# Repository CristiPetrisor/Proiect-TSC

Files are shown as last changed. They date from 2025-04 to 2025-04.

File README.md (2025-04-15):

# OpenBook E-Reader - Readme

**Proiect TSC - Caramida-Stoian Petrisor-Cristian**

## Prezentare pe scurt

OpenBook este un e-reader open-source bazat pe ESP32-C6, dotat cu ecran e-paper de 7.5", senzori de mediu, sistem de alimentare cu baterie și conectivitate Wi-Fi și USB-C. Documentul prezintă structura hardware și componentele integrate.

## Diagramă Bloc

```
           +-------------------------+
           |         Battery          |
           +------------+------------+
                        |
                        v
           +-------------------------+
           |     Charging IC (USB-C)  |
           +------------+------------+
                        |
                        v
           +-------------------------+
           |         LDO              |  ---> 3.3V
           +------------+------------+
                        |
     +------------------+-------------------+------------------+
     |                  |                   |                  |
     v                  v                   v                  v
+------------+   +--------------+   +---------------+   +-----------------+
|   ESP32    |<->|    Display   |<->|    BME688     |<->|  Tactile Buttons|
|    -C6     |   |   (SPI: 4W)   |   |   (I2C Bus)   |   |   (GPIO + RC)   |
+------------+   +--------------+   +---------------+   +-----------------+
     |                  ^                    ^                    ^
     |                  |                    |                    |
     |                  |              Pull-up Resistors     Debouncing RC
     |                  |
     v                  |
+----------------------------+
|      USB-C Connector       |
| (USB Data ↔ ESP32 USB)     |
| (ESD & Termination Prot.)  |
+----------------------------+
```

## Lista BOM

| **Componentă** | **Part Number** | **Descriere** | **Furnizor (Mouser)** | **Datasheet** |
|---|---|---|---|---|
| 1 | ADAFRUIT_LEDCHIP-LED0603 | - | LED | ADAFRUIT_CHIP-LED0603 | CHG_LED | [link](https://www.mouser.com/ProductDetail/Adafruit/CHIP-LED0603) | [datasheet](https://www.mouser.com/datasheet/2/737/CHIP-LED0603-1877199.pdf) |
| 1 | SJ | - | SMD solder JUMPER | SJ | SJ1 | [link](https://www.mouser.com/ProductDetail/TE-Connectivity/1-2176091-2) | [datasheet](https://www.mouser.com/datasheet/2/418/1-2176091-2-1817091.pdf) |
| 1 | ESP32_WROVER_EAGLE-LTSPICE_RR0402  | 0.47Ω | Rezistor | ESP32_WROVER_EAGLE-LTSPICE_R0402| R3 | [link](https://www.mouser.com/ProductDetail/Vishay/CRCW04020047ZRT7) | [datasheet](https://www.mouser.com/datasheet/2/427/crcwce-1764191.pdf) |
| 1 | ESP32_WROVER_EAGLE-LTSPICE_RR0402  | 100KΩ | Rezistor | ESP32_WROVER_EAGLE-LTSPICE_R0402| R1_PWRUSB | [link](https://www.mouser.com/ProductDetail/Vishay/CRCW0402100KFKED) | [datasheet](https://www.mouser.com/datasheet/2/427/crcwce-1764191.pdf) |
| 8 | EAGLE-LTSPICE_CC0402 | 100nF | Condensator | EAGLE-LTSPICE_C0402 | C1, C2, C4_USB, C6, C8, C9, C10, C_DELAY | [link](https://www.mouser.com/ProductDetail/Murata/GRM155R71C104KA88D) | [datasheet](https://www.mouser.com/datasheet/2/281/GRM155R71C104KA88D-1767201.pdf) |
| 1 | RCL_CPOL-EUCT3528 | 100µF | Condensator polarizat | RCL_CT3528 | C3 | [link](https://www.mouser.com/ProductDetail/Panasonic/EEE-FK1V101P) | [datasheet](https://www.mouser.com/datasheet/2/315/EEE-FK1V101P-1526881.pdf) |
| 10 | ESP32_WROVER_EAGLE-LTSPICE_RR0402  | 10KΩ | Rezistor | ESP32_WROVER_EAGLE-LTSPICE_R0402| R1, R1-PINH, R1_PINH1, R2-PINH, R2_PINH1, R4, R_BOOT, R_CHANGE, R_CL1, R_RESET | [link](https://www.mouser.com/ProductDetail/Vishay/CRCW040210K0FKED) | [datasheet](https://www.mouser.com/datasheet/2/427/crcwce-1764191.pdf) |
| 6 | ESP32_WROVER_EAGLE-LTSPICE_RR0402  | 10kΩ | Rezistor | ESP32_WROVER_EAGLE-LTSPICE_R0402| R5, R6, R7, R8, R9, R10 | [link](https://www.mouser.com/ProductDetail/Vishay/CRCW040210K0FKED) | [datasheet](https://www.mouser.com/datasheet/2/427/crcwce-1764191.pdf) |
| 1 | EAGLE-LTSPICE_CC0402 | 10µF | Condensator | EAGLE-LTSPICE_C0402 | C7 | [link](https://www.mouser.com/ProductDetail/Murata/GRM155R61A106ME44D) | [datasheet](https://www.mouser.com/datasheet/2/281/GRM155R61A106ME44D-1767201.pdf) |
| 1 | 112A-TAAR-R03_ATTEND | - | Micro SD Card Socket, Push-Push Type | 112ATAARR03ATTEND | J4 | [link](https://www.mouser.com/ProductDetail/Attend/112A-TAAR-R03) | [datasheet](https://www.mouser.com/datasheet/2/828/112A-TAAR-R03-1222862.pdf) |
| 1 | ESP32_WROVER_EAGLE-LTSPICE_RR0402  | 15Ω | Rezistor | ESP32_WROVER_EAGLE-LTSPICE_R0402| R_CAPACITOR  | [link](https://www.mouser.com/ProductDetail/Vishay/CRCW040215R0FKED) | [datasheet](https://www.mouser.com/datasheet/2/427/crcwce-1764191.pdf) |
| 1 | EAGLE-LTSPICE_CC0402 | 1µF | Condensator | EAGLE-LTSPICE_C0402 | C5 | [link](https://www.mouser.com/ProductDetail/Murata/GRM155R61A105KE15D) | [datasheet](https://www.mouser.com/datasheet/2/281/GRM155R61A105KE15D-1767201.pdf) |
| 10 | EAGLE-LTSPICE_CC0402 | 1µF/50V | Condensator ceramic multi-strat | 0402 | EPD_C1, EPD_C2, EPD_C5, EPD_C6, EPD_C7, EPD_C8, EPD_C9, EPD_C10, EPD_C11, EPD_C12 | [link](https://www.mouser.com/ProductDetail/Murata-Electronics/GRM155R61A105KE15D) | [datasheet](https://www.mouser.com/datasheet/2/281/1/GRM155R61A105KE15_01A-1983730.pdf) |

---

## Detalii Functionalitate Hardware

## ESP32-C6-WROOM-1-N8

- **Rol**: Controler principal, conectivitate wireless și suport periferice.
- **Specificații**: 160MHz, 512KB SRAM, 8MB Flash.
- **Interfețe**:
  - **SPI**: Display e-paper, memorie Flash, card Micro SD.
  - **I2C**: Senzor BME680, monitorizare baterie (MAX17048), RTC (DS3231).
  - **GPIO**: Interacțiune cu butoane și LED-uri.
  - **UART**: Debugging și comunicare serială.

## Senzor BME680

- **Funcționalitate**: Măsoară temperatură, umiditate, presiune atmosferică și calitate aer.
- **Interfață**: I2C la 400kHz.
- **Consum**: Sub 1mA activ, sub 1µA în repaus.

## Sistem de Alimentare

- **Baterie**: Li-Po 2500mAh, 3.7V.
- **Încărcare**: Controlată de MCP73831 prin USB-C, cu capacitate de 1A.
- **Monitorizare**: MAX17048 prin I2C.
- **Consum energetic**:
  - Activ (Wi-Fi + ecran actualizat): ~150mA.
  - Standby (doar ecran afișat): ~10mA.
  - Deep Sleep: Sub 50µA.
  - **Autonomie estimată**: Aproximativ o săptămână (~250 ore cu un consum mediu de 10mA).

## Display E-Paper
  
-Dimensiune: 7.5 inch, cu o rezoluție de 800x480 pixeli și un contrast de 8:1.
-Conectivitate: Se conectează prin interfața SPI și are linii dedicate pentru control și resetare.
-Consum de energie: Sub 50mA în timpul actualizării imaginii și aproape zero în modul standby.

## Butoane de Navigare

- Butoane tactile Panasonic EVQPUJ02K cu rezistență pull-up de 10KΩ.

## USB-C

- **Rol**: Încărcare (5V/1A) și transfer de date (USB 2.0).
- **Protecție**: Diode ESD (USBLC6-2SC6Y) pentru siguranță la supratensiune.

## Configurare Pini ESP32-C6

| **Pin ESP32-C6** | **Funcție** | **Componentă** | **Rol** |
|---|---|---|---|
| GPIO0 | BOOT_BUTTON | Buton | Mod boot la inițializare |
| GPIO1 | RESET_BUTTON | Buton | Reset manual |
| GPIO2 | CHANGE_BUTTON | Buton | Schimbare meniuri |
| GPIO3 | EPD_CS | Display E-Paper | Chip Select pentru SPI |
| GPIO4 | EPD_DC | Display E-Paper | Control Date/Comenzi |
| GPIO5 | EPD_RST | Display E-Paper | Reset display |
| GPIO6 | EPD_BUSY | Display E-Paper | Detectare stare refresh |
| GPIO7 | SPI_MOSI | Display, Flash, SD | Linii de date SPI |
| GPIO8 | SPI_MISO | Display, Flash, SD | Linie de date SPI (citire) |
| GPIO9 | SPI_SCK | Display, Flash, SD | Semnal de ceas SPI |
| GPIO10 | FLASH_CS | Memorie Flash | Chip Select pentru memorie |
| GPIO11 | SD_CS | Card Micro SD | Chip Select pentru card SD |
| GPIO12 | I2C_SDA | BME680, MAX17048, DS3231 | Linie de date pentru I2C |
| GPIO13 | I2C_SCL | BME680, MAX17048, DS3231 | Linie de ceas pentru I2C |
| GPIO14 | CHG_LED | LED | Indică procesul de încărcare |
| GPIO15 | UART_TX | Debugging | Transmitere date seriale |
| GPIO16 | UART_RX | Debugging | Recepție date seriale |
| GPIO17 | USB_D+ | USB-C | Linie de date USB pozitivă |
| GPIO18 | USB_D- | USB-C | Linie de date USB negativă |

Notă: Pinii sunt alocați conform specificațiilor ESP32-C6 și cerințelor dispozitivului OpenBook. Anumiți pini sunt multifuncționali și pot fi utilizați în diferite configurații.

Poze Schematic si PCB 






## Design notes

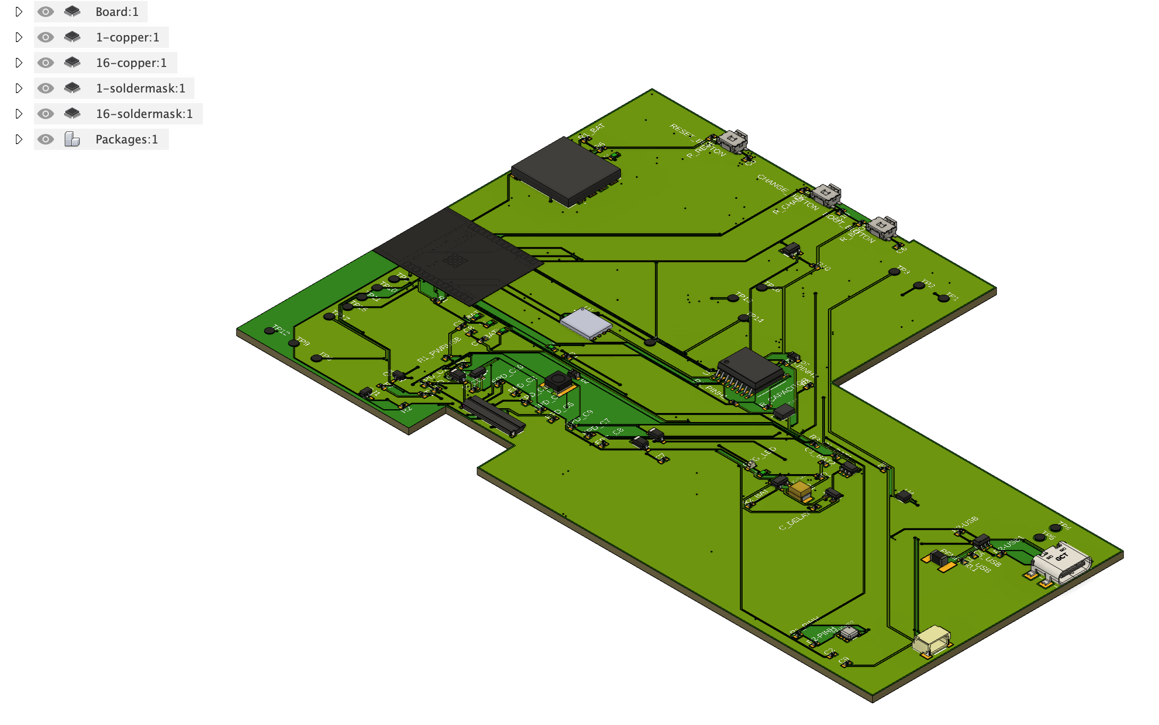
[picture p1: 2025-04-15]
Images/Screenshot 2025-04-15 at 20.33.14.png

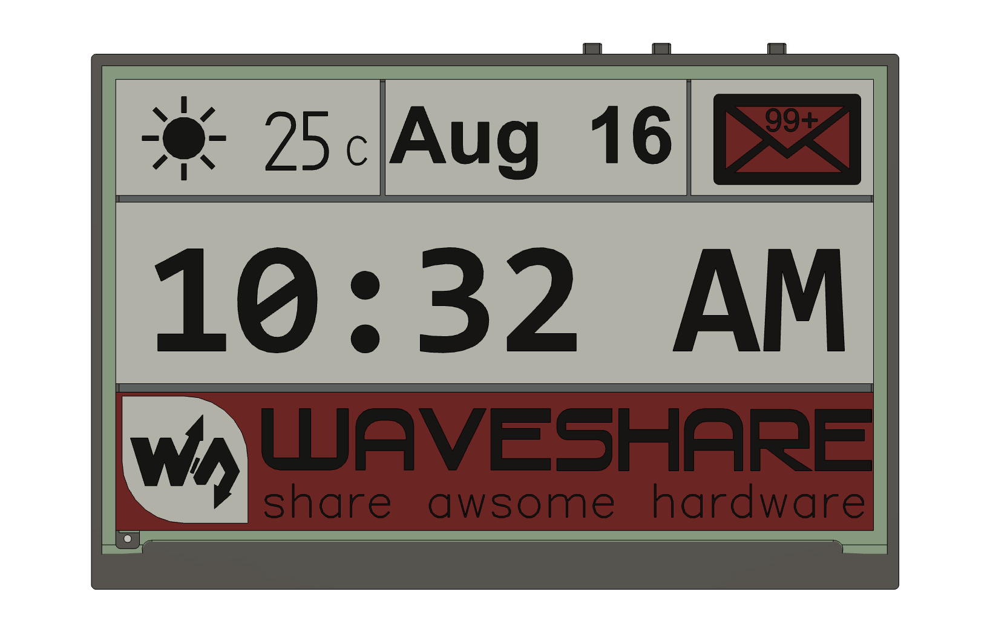
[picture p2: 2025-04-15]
Images/Screenshot 2025-04-15 at 20.50.41.png

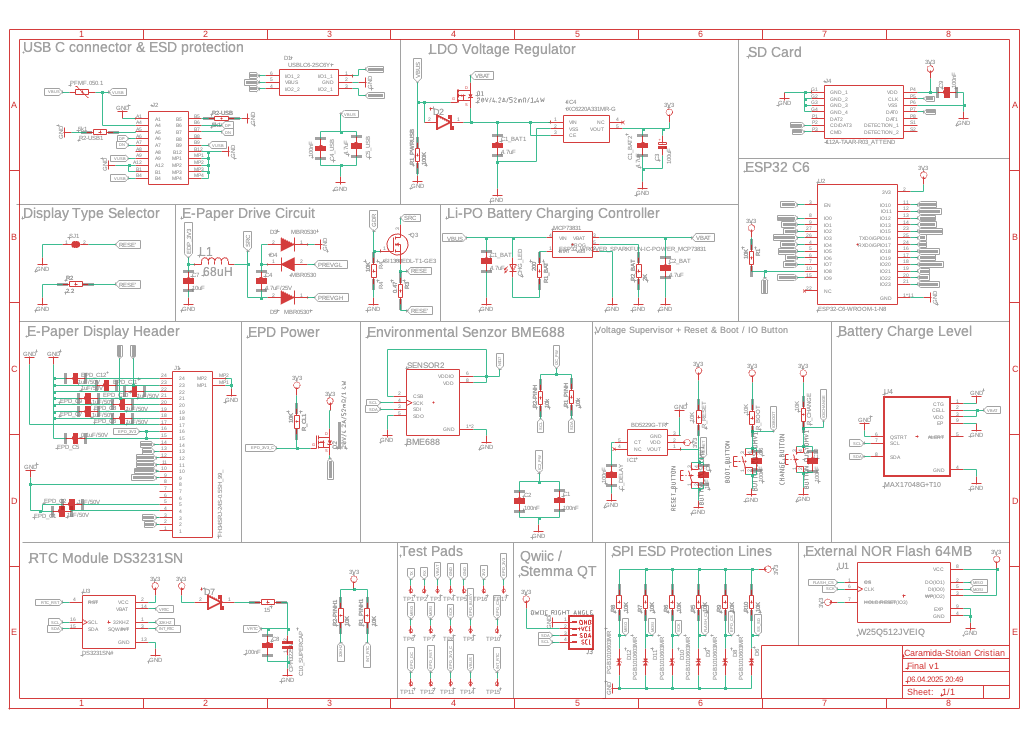
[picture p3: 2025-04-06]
Images/Sch.png

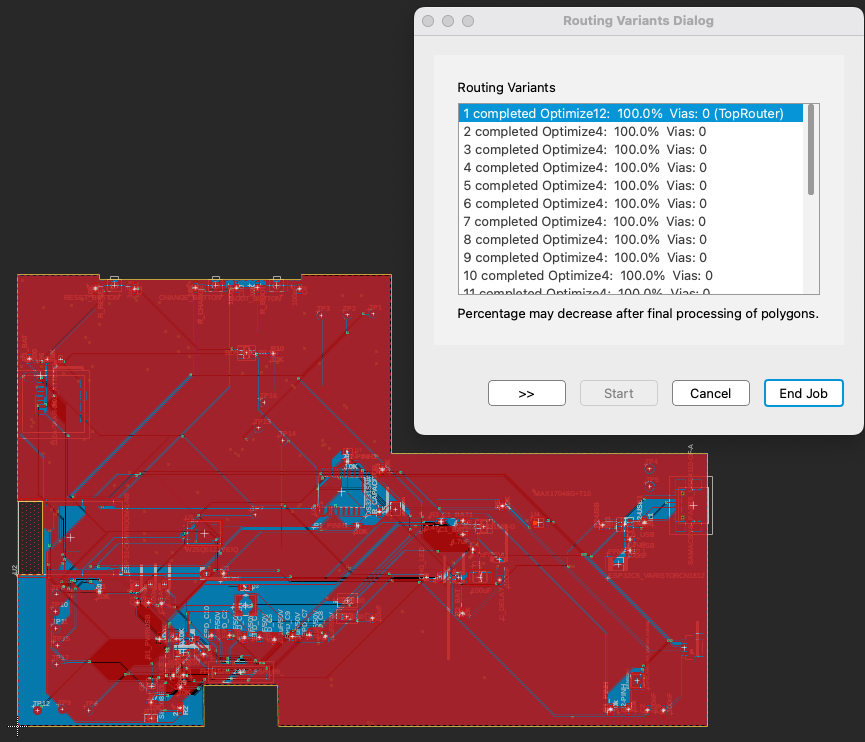
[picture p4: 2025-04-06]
Images/PCB.png

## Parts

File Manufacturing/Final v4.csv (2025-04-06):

Qty | Value | Device | Package | Parts | Description | ARROW_PART_NUMBER | ARROW_PRICE-STOCK | AVAILABILITY | CENTROID_NOT_SPECIFIED | CHECK_PRICES | COPYRIGHT | DATASHEET | DESCRIPTION | DIGIKEY_DESCRIPTION | DIGIKEY_PART_NUMBER | HEIGHT | LEAD_FREE | MANUFACTURER_NAME | MANUFACTURER_PART_NUMBER | MF | MFR_NAME | MOUSER_PART_NUMBER | MOUSER_PRICE-STOCK | MOUSER_TESTING_PART_NUMBER | MOUSER_TESTING_PRICE-STOCK | MP | MPN | PACKAGE | POPULARITY | PREFIX | PRICE | PROD_ID | PURCHASE-URL | ROHS | SNAPEDA_LINK | SPICEMODEL | SPICEPREFIX | TEMPERATURE_RANGE_HIGH | TEMPERATURE_RANGE_LOW | TP_SIGNAL_NAME | VALUE
1 |  | ADAFRUIT_LEDCHIP-LED0603 | ADAFRUIT_CHIP-LED0603 | CHG_LED | LED
1 |  | SJ | SJ | SJ1 | SMD solder JUMPER |  |  |  |  |  |  |  |  |  |  |  |  |  |  |  |  |  |  |  |  |  |  |  | 3
1 | 0.1uF/50V | EAGLE-LTSPICE_CC0402 | EAGLE-LTSPICE_C0402 | EPD_C5 | CAPACITOR, European symbol |  |  |  |  |  |  |  |  |  |  |  |  |  |  |  |  |  |  |  |  |  |  |  |  |  |  |  |  |  |  | NONE | C
1 | 0.47 | ESP32_WROVER_EAGLE-LTSPICE_RR0402 | ESP32_WROVER_EAGLE-LTSPICE_R0402 | R3 | RESISTOR, European symbol |  |  |  |  |  |  |  |  |  |  |  |  |  |  |  |  |  |  |  |  |  |  |  |  |  |  |  |  |  |  | NONE | R
1 | 100K | ESP32_WROVER_EAGLE-LTSPICE_RR0402 | ESP32_WROVER_EAGLE-LTSPICE_R0402 | R1_PWRUSB | RESISTOR, European symbol |  |  |  |  |  |  |  |  |  |  |  |  |  |  |  |  |  |  |  |  |  |  |  |  |  |  |  |  |  |  | NONE | R
2 | 100nF | EAGLE-LTSPICE_CC0402 | EAGLE-LTSPICE_C0402 | C6, C10 | CAPACITOR, European symbol |  |  |  |  |  |  |  |  |  |  |  |  |  |  |  |  |  |  |  |  |  |  |  |  |  |  |  |  |  |  | NONE | C
6 | 100nF | ESP32_WROVER_EAGLE-LTSPICE_CC0402 | ESP32_WROVER_EAGLE-LTSPICE_C0402 | C1, C2, C4_USB, C8, C9, C_DELAY | CAPACITOR, European symbol |  |  |  |  |  |  |  |  |  |  |  |  |  |  |  |  |  |  |  |  |  |  |  |  |  |  |  |  |  |  | NONE | C
1 | 100uF | RCL_CPOL-EUCT3528 | RCL_CT3528 | C3 | POLARIZED CAPACITOR, European symbol |  |  |  |  |  |  |  |  |  |  |  |  |  |  |  |  |  |  |  |  |  |  |  | 0 |  |  |  |  |  |  |  | C
14 | 10K | ESP32_WROVER_EAGLE-LTSPICE_RR0402 | ESP32_WROVER_EAGLE-LTSPICE_R0402 | R1, R1_PINH1, R2-PINH1, R4, R5, R6, R7, R8, R9, R10, R_BOOT, R_CHANGE, R_CL1, R_RESET | RESISTOR, European symbol |  |  |  |  |  |  |  |  |  |  |  |  |  |  |  |  |  |  |  |  |  |  |  |  |  |  |  |  |  |  | NONE | R
2 | 10k | ESP32_WROVER_EAGLE-LTSPICE_RR0402 | ESP32_WROVER_EAGLE-LTSPICE_R0402 | R1_PINH, R2-PINH | RESISTOR, European symbol |  |  |  |  |  |  |  |  |  |  |  |  |  |  |  |  |  |  |  |  |  |  |  |  |  |  |  |  |  |  | NONE | R
1 | 10uF | ESP32_WROVER_EAGLE-LTSPICE_CC0402 | ESP32_WROVER_EAGLE-LTSPICE_C0402 | C7 | CAPACITOR, European symbol |  |  |  |  |  |  |  |  |  |  |  |  |  |  |  |  |  |  |  |  |  |  |  |  |  |  |  |  |  |  | NONE | C
1 | 112A-TAAR-R03_ATTEND | 112A-TAAR-R03_ATTEND | 112ATAARR03ATTEND | J4 | Micro SD Card Socket, Push-Push Type, Top Mount, SMT, H=1.83mm, 10u |  |  |  |  |  |  |  | Micro SD Card Socket | Push-Push Type | Top Mount | SMT | H=1.83mm | 10u |  |  | 1.9mm |  | ATTEND | 112A-TAAR-R03 ATTEND
1 | 15 | ESP32_WROVER_EAGLE-LTSPICE_RR0402 | ESP32_WROVER_EAGLE-LTSPICE_R0402 | R_CAPACITOR | RESISTOR, European symbol |  |  |  |  |  |  |  |  |  |  |  |  |  |  |  |  |  |  |  |  |  |  |  |  |  |  |  |  |  |  | NONE | R
1 | 1uF | EAGLE-LTSPICE_CC0402 | EAGLE-LTSPICE_C0402 | C5 | CAPACITOR, European symbol |  |  |  |  |  |  |  |  |  |  |  |  |  |  |  |  |  |  |  |  |  |  |  |  |  |  |  |  |  |  | NONE | C
9 | 1uF/50V | EAGLE-LTSPICE_CC0402 | EAGLE-LTSPICE_C0402 | EPD_C1, EPD_C2, EPD_C6, EPD_C7, EPD_C8, EPD_C9, EPD_C10, EPD_C11, EPD_C12 | CAPACITOR, European symbol |  |  |  |  |  |  |  |  |  |  |  |  |  |  |  |  |  |  |  |  |  |  |  |  |  |  |  |  |  |  | NONE | C
1 | 2.2 | ESP32_WROVER_EAGLE-LTSPICE_RR0402 | ESP32_WROVER_EAGLE-LTSPICE_R0402 | R2 | RESISTOR, European symbol |  |  |  |  |  |  |  |  |  |  |  |  |  |  |  |  |  |  |  |  |  |  |  |  |  |  |  |  |  |  | NONE | R
1 | 200 | ESP32_WROVER_EAGLE-LTSPICE_RR0402 | ESP32_WROVER_EAGLE-LTSPICE_R0402 | R1_BAT | RESISTOR, European symbol |  |  |  |  |  |  |  |  |  |  |  |  |  |  |  |  |  |  |  |  |  |  |  |  |  |  |  |  |  |  | NONE | R
2 | 20V/4.2A/52mΩ/1.4W | ESP32_WROVER_SPARKFUN-DISCRETESEMI_MOSFET_PCH-DMG2305UX-7 | ESP32_WROVER_SPARKFUN-DISCRETESEMI_SOT23-3 | Q1, Q2 | P-channel MOSFETs |  |  |  |  |  |  |  |  |  |  |  |  |  |  |  |  |  |  |  |  |  |  |  |  |  |  | TRAN-14388 |  |  |  |  |  |  |  |  | 20V/4.2A/52mΩ/1.4W
1 | 2K | ESP32_WROVER_EAGLE-LTSPICE_RR0402 | ESP32_WROVER_EAGLE-LTSPICE_R0402 | R2_BAT | RESISTOR, European symbol |  |  |  |  |  |  |  |  |  |  |  |  |  |  |  |  |  |  |  |  |  |  |  |  |  |  |  |  |  |  | NONE | R
5 | 4.7uF | ESP32_WROVER_EAGLE-LTSPICE_CC0402 | ESP32_WROVER_EAGLE-LTSPICE_C0402 | C1_BAT, C1_BAT1, C1_BAT2, C2_BAT, C5_USB | CAPACITOR, European symbol |  |  |  |  |  |  |  |  |  |  |  |  |  |  |  |  |  |  |  |  |  |  |  |  |  |  |  |  |  |  | NONE | C
1 | 4.7uF/25V | ESP32_WROVER_EAGLE-LTSPICE_CC0402 | ESP32_WROVER_EAGLE-LTSPICE_C0402 | C4 | CAPACITOR, European symbol |  |  |  |  |  |  |  |  |  |  |  |  |  |  |  |  |  |  |  |  |  |  |  |  |  |  |  |  |  |  | NONE | C
2 | 5k1 | ESP32_WROVER_EAGLE-LTSPICE_RR0402 | ESP32_WROVER_EAGLE-LTSPICE_R0402 | R2-USB, R2-USB1 | RESISTOR, European symbol |  |  |  |  |  |  |  |  |  |  |  |  |  |  |  |  |  |  |  |  |  |  |  |  |  |  |  |  |  |  | NONE | R
1 | 68uH | 744043680IND_4828-WE-TPC_WRE | IND_4828-WE-TPC_WRE | L1 |  |  |  |  |  |  | Copyright (C) 2024 Ultra Librarian. All rights reserved. |  |  |  |  |  |  |  | 744043680 |  | Wurth Electronics
1 | BD5229G-TR | BD5229G-TR | SOT95P280X125-5N | IC1 | Voltage Detector with Adjustable Delay Time: CMOS processes are utilized to develop high precision, low current consumption CMOS reset ICs that allow arbitrary setting of the delay time. The extensive lineup includes both Nch Open Drain and CMOS output types in a wide range of detection voltages (from 2.3V to 6.0V, in 0.1V steps), enabling selection of the ideal solution based on customer requirements. In addition, the entire series is of course both lead-free and RoHS-compliant. |  |  |  |  |  |  |  | Voltage Detector with Adjustable Delay Time: CMOS processes are utilized to develop high precision | low current consumption CMOS reset ICs that allow arbitrary setting of the delay time. The extensive lineup includes both Nch Open Drain and CMOS output types in a wide range of detection voltages (from 2.3V to 6.0V | in 0.1V steps) | enabling selection of the ideal solution based on customer requirements. In addition | the entire series is of course both lead-free and RoHS-compliant. |  |  | 1.25mm |  | ROHM Semiconductor | BD5229G-TR |  |  | 755-BD5229G-TR | https://www.mouser.co.uk/ProductDetail/ROHM-Semiconductor/BD5229G-TR?qs=4kLU8WoGk0vvnhrrYwdszw%3D%3D
3 | BUTTON_CUSYOMV1 | BUTTON_CUSYOMV1 | MYBUTTON | BOOT_BUTTON, CHANGE_BUTTON, RESET_BUTTON
1 | CPH3225A | CPH3225A | CAPCP3225X100N | C10_SUPERCAP | Cap 0.011F 3.3V 1210 Flat Check availability |  |  | Not in stock |  | https://www.snapeda.com/parts/CPH3225A/Seiko+Instruments/view-part/?ref=eda |  |  | 11 mF (EDLC) Supercapacitor 3.3 V 1210 (3225 Metric) - - |  |  |  |  |  |  | Seiko Instruments |  |  |  |  |  | CPH3225A |  | 1210 Seiko |  |  | None |  | https://www.snapeda.com/api/url_track_click_mouser/?unipart_id=562593&manufacturer=Seiko Instruments&part_name=CPH3225A&search_term=None |  | https://www.snapeda.com/parts/CPH3225A/Seiko+Instruments/view-part/?ref=snap
1 | DS3231SN# | DS3231SN# | SOIC127P1032X265-16N | U3 | Real Time Clock Serial 16-Pin SOIC W T/R Check availability |  |  | In Stock |  | https://www.snapeda.com/parts/DS3231SN%23/Analog+Devices/view-part/?ref=eda |  |  | Extremely Accurate I²C-Integrated RTC/TCXO/Crystal |  |  |  |  |  |  | Analog Devices |  |  |  |  |  | DS3231SN# |  | SOIC-16 Maxim |  |  | None |  | https://www.snapeda.com/api/url_track_click_mouser/?unipart_id=99048&manufacturer=Analog Devices&part_name=DS3231SN#&search_term=None |  | https://www.snapeda.com/parts/DS3231SN%23/Analog+Devices/view-part/?ref=snap
1 | ESP32-C6-WROOM-1-N8 | ESP32-C6-WROOM-1-N8 | XCVR_ESP32-C6-WROOM-1-N8 | U2 | Check availability |  |  | In Stock |  | https://www.snapeda.com/parts/ESP32-C6-WROOM-1-N8/Espressif+Systems/view-part/?ref=eda |  |  | Multiprotocol Modules ESP32-C6 module | Wi-Fi 6 in 2.4 GHz band | Bluetooth 5 | Zigbee 3.0 and Thread. ESP34-WROOM Compatible - ENGINEERING SAMPLE |  |  |  |  |  |  | Espressif Systems |  |  |  |  |  | ESP32-C6-WROOM-1-N8 |  | None |  |  | None |  |  |  | https://www.snapeda.com/parts/ESP32-C6-WROOM-1-N8/Espressif+Systems/view-part/?ref=snap
1 | ESP32C6_VARISTORCN1812 | ESP32C6_VARISTORCN1812 | ESP32C6_VARISTOR_CT/CN1812 | PFMF.050.1 | VARISTOR |  |  |  |  |  |  |  |  |  |  |  |  |  |  |  |  |  |  |  |  |  |  |  | 0
2 | ESP32_WROVER_AVX---SD0805S020S1R0_AVX_SD0805S020S1R0_0_0AVX_SD0805S020S1R0_0_0 | ESP32_WROVER_AVX---SD0805S020S1R0_AVX_SD0805S020S1R0_0_0AVX_SD0805S020S1R0_0_0 | ESP32_WROVER_AVX---SD0805S020S1R0_AVX_SD0805S020S1R0_0 | D2, D7 | Schottky Barrier Rectifier Diode |  |  |  | No |  |  | http://datasheets.avx.com/schottky.pdf |  | DIODE SCHOTTKY 20V 1A 0805 | 478-7800-1-ND |  | yes |  |  | AVX |  | 581-SD0805S020S1R0 |  |  |  |  |  | 0805 (2012 metric) |  | D |  |  |  | yes |  |  |  | +125°C | -55°C
1 | ESP32_WROVER_BME680_BME680 | ESP32_WROVER_BME680_BME680 | ESP32_WROVER_BME680_PSON80P300X300X100-8N | SENSOR2 | Integrated Environmental Unit |  |  | Unavailable |  |  |  |  | Integrated Environmental Unit |  |  |  |  |  |  | Bosch Sensortec |  |  |  |  |  | BME680 |  | LGA-8 Bosch Tools |  |  | None
1 | ESP32_WROVER_SPARKFUN-IC-POWER_MCP73831 | ESP32_WROVER_SPARKFUN-IC-POWER_MCP73831 | ESP32_WROVER_SPARKFUN-IC-POWER_SOT23-5 | MCP73831 | MCP73831T Li-Ion, Li-Pol Controller |  |  |  |  |  |  |  |  |  |  |  |  |  |  |  |  |  |  |  |  |  |  |  |  |  |  | IC-09995
1 | FH34SRJ-24S-0.5SH_99_ | FH34SRJ-24S-0.5SH_99_ | FH34SRJ24S05SH99 | J1 | (0.50mm) Surface Mount, Right Angle |  |  |  |  |  |  |  | 24 Position FFC | FPC Connector Contacts | (0.50mm) Surface Mount | Right Angle |  |  | 1.1mm |  | Hirose | FH34SRJ-24S-0.5SH(99) |  |  | 798-FH34SRJ24S05SH99 | https://www.mouser.co.uk/ProductDetail/Hirose-Connector/FH34SRJ-24S-0.5SH99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
1 | MAX17048G+T10 | MAX17048G+T10 | SON50P200X200X80-9N | U4 | Check availability |  |  | In Stock |  | https://www.snapeda.com/parts/MAX17048G+T10/Analog+Devices/view-part/?ref=eda |  |  | 3µA 1-Cell/2-Cell Fuel Gauge with ModelGauge |  |  |  |  |  |  | Analog Devices |  |  |  |  |  | MAX17048G+T10 |  | TDFN-8 Maxim |  |  | None |  | https://www.snapeda.com/api/url_track_click_mouser/?unipart_id=329239&manufacturer=Analog Devices&part_name=MAX17048G+T10&search_term=None |  | https://www.snapeda.com/parts/MAX17048G+T10/Analog+Devices/view-part/?ref=snap
3 | MBR0530 | MBR0530 | SOD3716X135N | D3, D4, D5 | ON SEMICONDUCTOR - MBR0530 - DIODE, SCHOTTKY, 0.5A, 30V, SOD-123 |  |  | In Stock |  | https://www.snapeda.com/parts/MBR0530/Onsemi/view-part/?ref=eda |  |  | Diode Schottky 30 V 500mA Surface Mount SOD-123 |  |  |  |  |  |  | ON Semiconductor |  |  |  |  |  | MBR0530 |  | SOD-123-2 ON Semiconductor |  |  | None |  | https://www.snapeda.com/api/url_track_click_mouser/?unipart_id=179458&manufacturer=ON Semiconductor&part_name=MBR0530&search_term=None |  | https://www.snapeda.com/parts/MBR0530/Onsemi/view-part/?ref=snap
6 | PGB1010603MR | PGB1010603MR | DIOC1608X36N | D6, D8, D9, D10, D11, D12 | Check availability |  |  | In Stock |  | https://www.snapeda.com/parts/PGB1010603MR/Littelfuse/view-part/?ref=eda |  |  | 150V (Typ) Clamp - Ipp Tvs Diode Surface Mount 0603 (1608 Metric) |  |  |  |  |  |  | Littelfuse Inc. |  |  |  |  |  | PGB1010603MR |  | 0603 Littelfuse Inc. |  |  | None |  | https://www.snapeda.com/api/url_track_click_mouser/?unipart_id=5659453&manufacturer=Littelfuse Inc.&part_name=PGB1010603MR&search_term=None |  | https://www.snapeda.com/parts/PGB1010603MR/Littelfuse/view-part/?ref=snap
1 | QWIIC_RIGHT_ANGLE | QWIIC_CONNECTORJS-1MM | JST04_1MM_RA | J3 | SparkFun I2C Standard Qwiic Connector |  |  |  |  |  |  |  |  |  |  |  |  |  |  |  |  |  |  |  |  |  |  |  |  |  |  | CONN-13694 |  |  |  |  |  |  |  |  | QWIIC_RIGHT_ANGLE
1 | SAMACSYS_PARTS_USB4110-GF-A | SAMACSYS_PARTS_USB4110-GF-A | SAMACSYS_PARTS_USB4110GFA | J2 | CONN USB 2.0 TYPE-C R/A SMT |  |  |  |  |  |  |  | CONN USB 2.0 TYPE-C R/A SMT |  |  | 3.26mm |  | GCT (GLOBAL CONNECTOR TECHNOLOGY) | USB4110-GF-A |  |  | 640-USB4110-GF-A | https://www.mouser.co.uk/ProductDetail/GCT/USB4110-GF-A?qs=KUoIvG%2F9IlYiZvIXQjyJeA%3D%3D
1 | SI1308EDL-T1-GE3 | SI1308EDL-T1-GE3 | SOT65P210X110-3N | Q3 | MOSFET N-Ch 30V 1.5A TrenchFET SC70 Vishay Si1308EDL-T1-GE3 N-channel MOSFET Transistor, 1.5 A, 30 V, 3-Pin SC-70 |  |  | In Stock |  | https://www.snapeda.com/parts/SI1308EDL-T1-GE3/Vishay+Siliconix/view-part/?ref=eda |  |  | Si1308EDL-T1-GE3 N-channel MOSFET Transistor | 1.5 A | 30 V | 3-Pin SC-70 | Siliconix / Vishay SI1308EDL-T1-GE3 |  |  |  |  |  |  | Vishay Siliconix |  |  |  |  |  | SI1308EDL-T1-GE3 |  | SOT-323 Vishay Semiconductor |  |  | None |  | https://www.snapeda.com/api/url_track_click_mouser/?unipart_id=274603&manufacturer=Vishay Siliconix&part_name=SI1308EDL-T1-GE3&search_term=None |  | https://www.snapeda.com/parts/SI1308EDL-T1-GE3/Vishay+Siliconix/view-part/?ref=snap
17 | TPTP20R | TPTP20R | TP20R | TP1, TP2, TP3, TP4, TP5, TP6, TP7, TP8, TP9, TP10, TP11, TP12, TP13, TP14, TP15, TP16, TP17 | Test pad |  |  |  |  |  |  |  |  |  |  |  |  |  |  |  |  |  |  |  |  |  |  |  | 2
1 | USBLC6-2SC6Y | USBLC6-2SC6Y | SOT95P280X145-6N | D1 | Low Cap. ESD Protection Auto SOT-23-6 STMicroelectronics USBLC6-2SC6Y, Dual Uni-Directional TVS Diode Array, 6-Pin SOT-23 |  |  | In Stock |  | https://www.snapeda.com/parts/USBLC6-2SC6Y/STMicroelectronics/view-part/?ref=eda |  |  | 17V Clamp 5A (8/20µs) Ipp Tvs Diode Surface Mount SOT-23-6 |  |  |  |  |  |  | STMicroelectronics |  |  |  |  |  | USBLC6-2SC6Y |  | SOT-23-6 STMicroelectronics |  |  | None |  |  |  | https://www.snapeda.com/parts/USBLC6-2SC6Y/STMicroelectronics/view-part/?ref=snap
1 | W25Q512JVEIQ | W25Q512JVEIQ | SON127P600X800X80-9N | U1 | Check availability |  |  | In Stock |  | https://www.snapeda.com/parts/W25Q512JVEIQ/Winbond+Electronics/view-part/?ref=eda |  |  | FLASH - NOR Memory IC 512Mb (64M x 8) SPI - Quad I/O 133 MHz 8-WSON (8x6) |  |  |  |  |  |  | Winbond Electronics |  |  |  |  |  | W25Q512JVEIQ |  | Package |  |  | None |  |  |  | https://www.snapeda.com/parts/W25Q512JVEIQ/Winbond+Electronics/view-part/?ref=snap
1 | XC6220A331MR-G | XC6220A331MR-G | SOT95P280X120-5N | IC4 | LDO Voltage Regulators |  |  |  |  |  |  |  | LDO Voltage Regulators |  |  | 1.2mm |  | Torex | XC6220A331MR-G |  |  | 865-XC6220A331MR-G | https://www.mouser.co.uk/ProductDetail/Torex-Semiconductor/XC6220A331MR-G?qs=AsjdqWjXhJ8ZSWznL1J0gg%3D%3D

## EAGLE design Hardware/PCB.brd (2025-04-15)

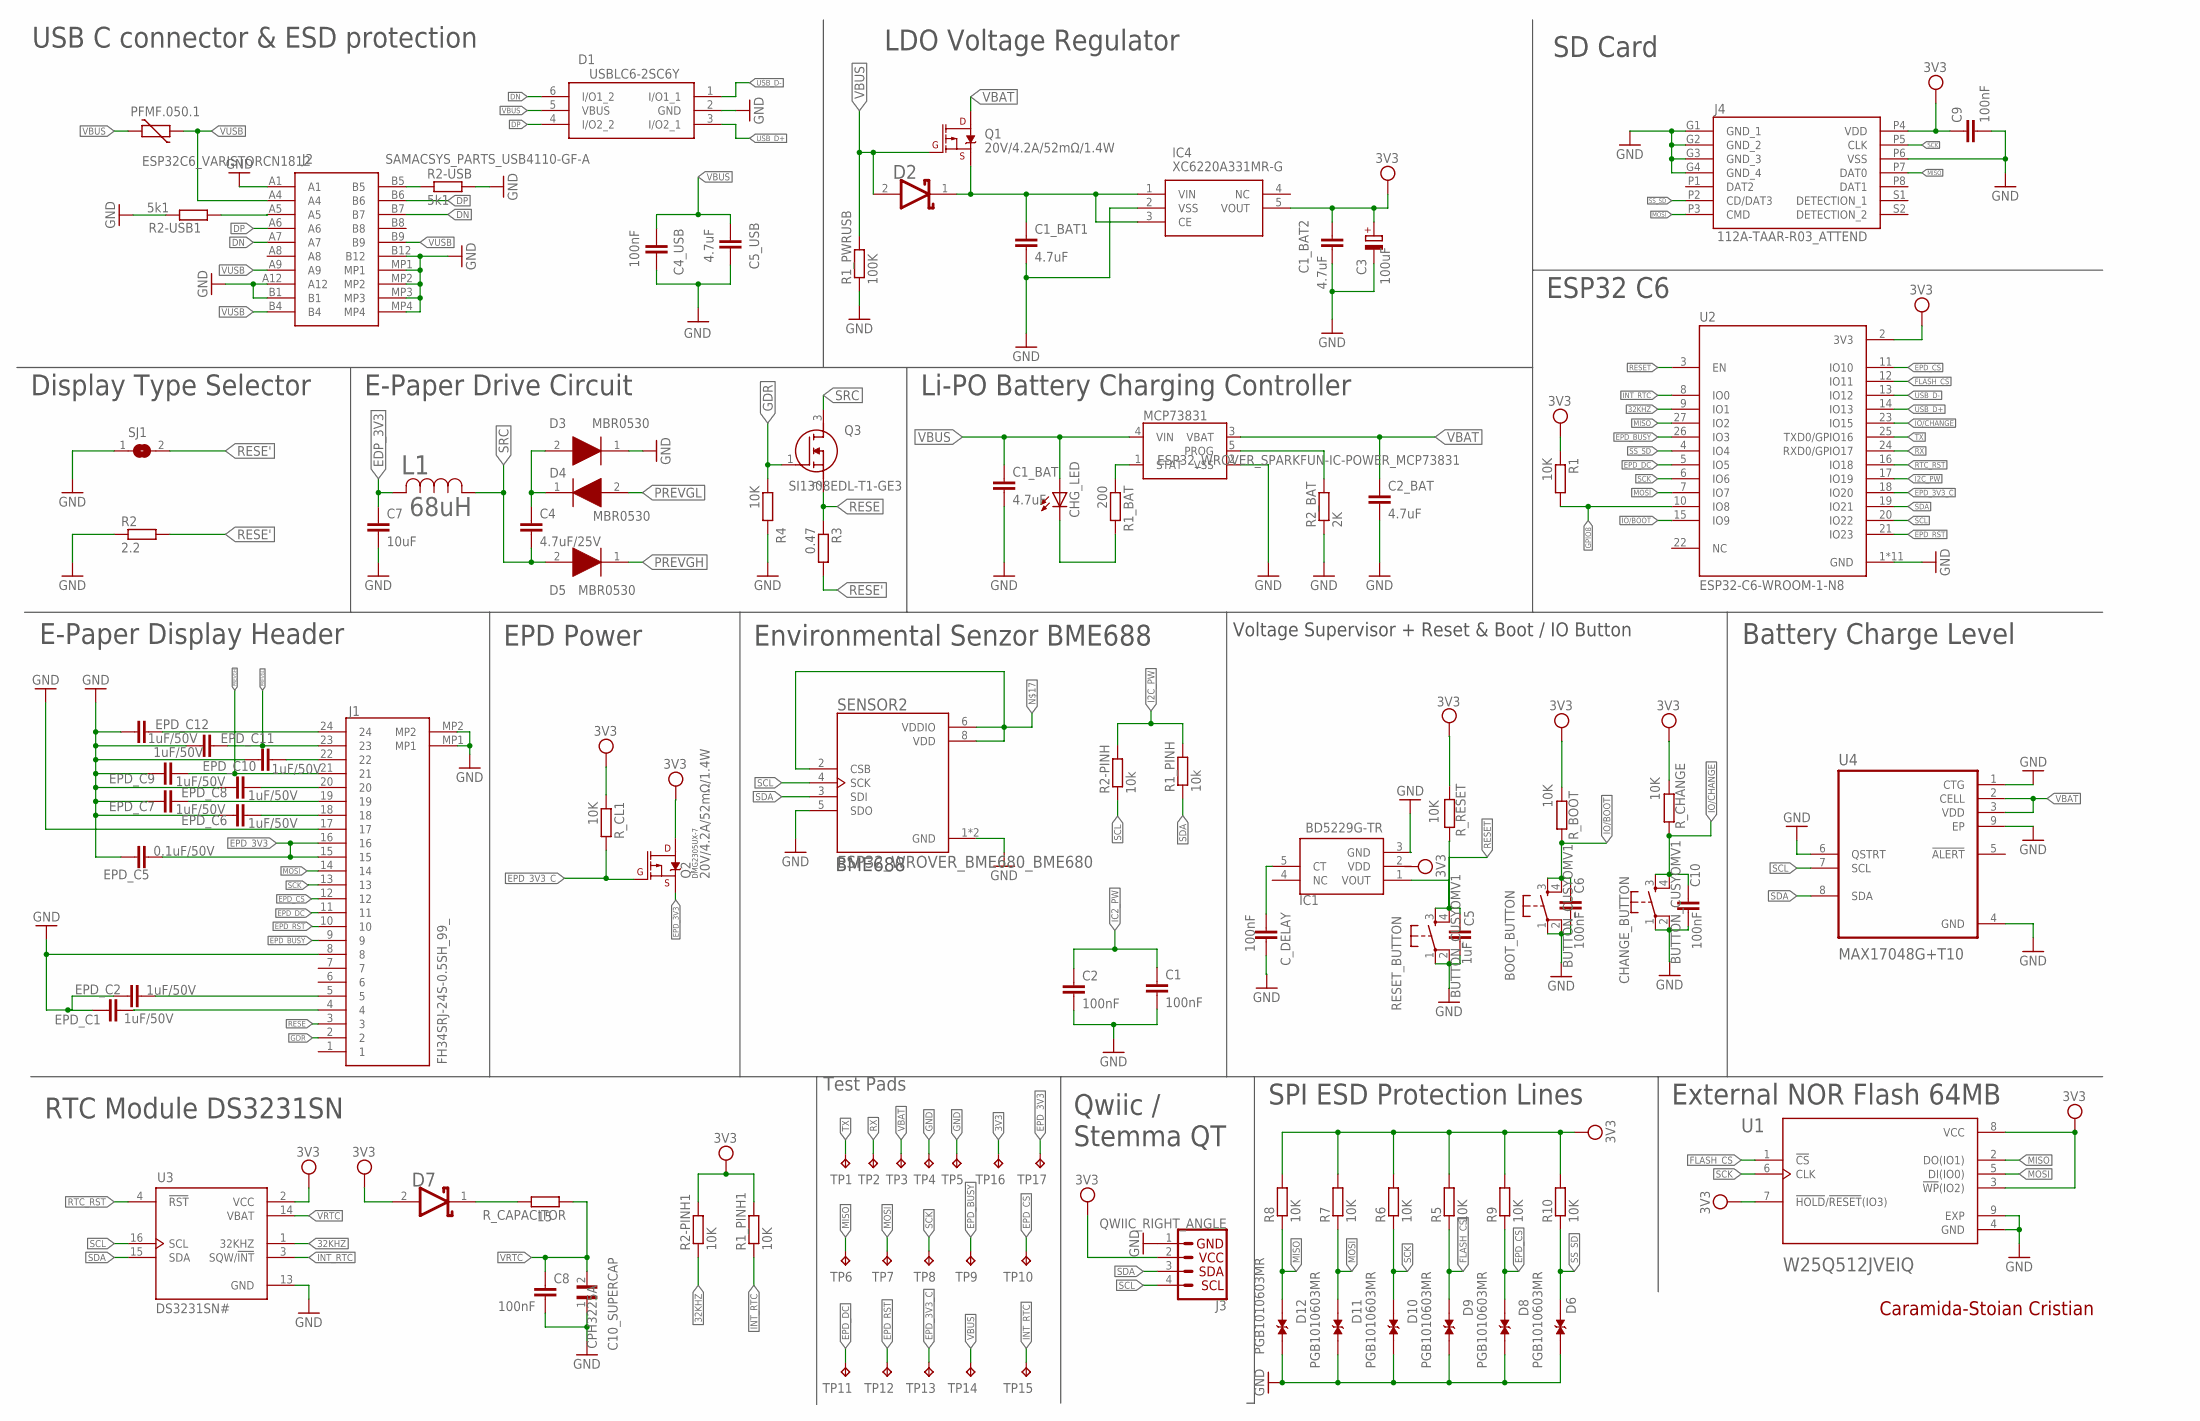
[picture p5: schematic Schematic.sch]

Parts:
BOOT_BUTTON: BUTTON_CUSYOMV1; MYBUTTON
C1, C2, C4_USB, C6, C8, C9, C10: 100nF; ESP32_WROVER_EAGLE-LTSPICE_C0402
C1_BAT, C1_BAT1, C1_BAT2, C2_BAT, C5_USB: 4.7uF; ESP32_WROVER_EAGLE-LTSPICE_C0402
C3: 100uF; RCL_CT3528
C4: 4.7uF/25V; ESP32_WROVER_EAGLE-LTSPICE_C0402
C5: 1uF; ESP32_WROVER_EAGLE-LTSPICE_C0402
C7: 10uF; ESP32_WROVER_EAGLE-LTSPICE_C0402
C10_SUPERCAP: CPH3225A; CAPCP3225X100N
CHANGE_BUTTON: BUTTON_CUSYOMV1; MYBUTTON
CHG_LED: ADAFRUIT_LEDCHIP-LED0603; ADAFRUIT_CHIP-LED0603
C_DELAY: 100nF; ESP32_WROVER_EAGLE-LTSPICE_C0402
D1: USBLC6-2SC6Y; SOT95P280X145-6N
D2, D7: ESP32_WROVER_AVX---SD0805S020S1R0_AVX_SD0805S020S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; ESP32_WROVER_AVX---SD0805S020S1R0_AVX_SD0805S020S1R0_0
D3, D4, D5: MBR0530; SOD3716X135N
D6, D8, D9, D10, D11, D12: PGB1010603MR; DIOC1608X36N
EPD_C1, EPD_C2, EPD_C6, EPD_C7, EPD_C8, EPD_C9, EPD_C10, EPD_C11, EPD_C12: 1uF/50V; ESP32_WROVER_EAGLE-LTSPICE_C0402
EPD_C5: 0.1uF/50V; ESP32_WROVER_EAGLE-LTSPICE_C0402
IC1: BD5229G-TR; SOT95P280X125-5N
IC4: XC6220A331MR-G; ESP32_WROVER_SPARKFUN-IC-POWER_SOT23-5
J1: FH34SRJ-24S-0.5SH_99_; FH34SRJ24S05SH99
J2: SAMACSYS_PARTS_USB4110-GF-A; SAMACSYS_PARTS_USB4110GFA
J3: QWIIC_RIGHT_ANGLE; JST04_1MM_RA
J4: 112A-TAAR-R03_ATTEND; 112ATAARR03ATTEND
L1: 68uH; IND_4828-WE-TPC_WRE
MCP73831: ESP32_WROVER_SPARKFUN-IC-POWER_MCP73831; ESP32_WROVER_SPARKFUN-IC-POWER_SOT23-5
PFMF.050.1: ESP32C6_VARISTORCN1812; ESP32C6_VARISTOR_CT/CN1812
Q1, Q2: 20V/4.2A/52mΩ/1.4W; ESP32_WROVER_SPARKFUN-DISCRETESEMI_SOT23-3
Q3: SI1308EDL-T1-GE3; SOT65P210X110-3N
R1, R1_PINH1, R2-PINH1, R4, R5, R6, R7, R8, R9, R10: 10K; ESP32_WROVER_EAGLE-LTSPICE_R0402
R1_BAT: 200; ESP32_WROVER_EAGLE-LTSPICE_R0402
R1_PINH, R2-PINH: 10k; ESP32_WROVER_EAGLE-LTSPICE_R0402
R1_PWRUSB: 100K; ESP32_WROVER_EAGLE-LTSPICE_R0402
R2: 2.2; ESP32_WROVER_EAGLE-LTSPICE_R0402
R2-USB, R2-USB1: 5k1; ESP32_WROVER_EAGLE-LTSPICE_R0402
R2_BAT: 2K; ESP32_WROVER_EAGLE-LTSPICE_R0402
R3: 0.47; ESP32_WROVER_EAGLE-LTSPICE_R0402
RESET_BUTTON: BUTTON_CUSYOMV1; MYBUTTON
R_BOOT: 10K; ESP32_WROVER_EAGLE-LTSPICE_R0402
R_CAPACITOR: 15; ESP32_WROVER_EAGLE-LTSPICE_R0402
R_CHANGE: 10K; ESP32_WROVER_EAGLE-LTSPICE_R0402
R_CL1: 10K; ESP32_WROVER_EAGLE-LTSPICE_R0402
R_RESET: 10K; ESP32_WROVER_EAGLE-LTSPICE_R0402
SENSOR2: ESP32_WROVER_BME680_BME680; ESP32_WROVER_BME680_PSON80P300X300X100-8N
SJ1: SJ; SOT65P210X110-3N
TP1, TP2, TP3, TP4, TP5, TP6, TP7, TP8, TP9, TP10, TP11, TP12, TP13, TP14, TP15, TP16, TP17: TPTP20R; TP20R
U1: W25Q512JVEIQ; SON127P600X800X80-9N
U2: ESP32-C6-WROOM-1-N8; XCVR_ESP32-C6-WROOM-1-N8
U3: DS3231SN#; SOIC127P1032X265-16N
U4: MAX17048G+T10; SON50P200X200X80-9N

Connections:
3V3: C1_BAT2.1, C3.+, C9.1, D7.2 (ANODE), IC4.5 (VOUT), J3.2, J4.P4 (VDD), Q2.3 (D), R1.1, R1_PINH1.2, R2-PINH1.2, R5.2, R6.2, R7.2, R8.2, R9.2, R10.2, R_BOOT.2, R_CHANGE.2, R_CL1.1, R_RESET.2, TP16.TP, U1.3 (!WP!(IO2)), U1.7 (!HOLD!/!RESET!(IO3)), U1.8 (VCC), U2.2 (3V3), U3.2 (VCC)
32KHZ: R2-PINH1.1, U2.9 (IO1), U3.1 (32KHZ)
DN: D1.6 (I/O1_2), J2.A7, J2.B7
DP: D1.4 (I/O2_2), J2.A6, J2.B6
EDP_3V3: C7.1, L1.2
EPD_3V3: EPD_C5.2, J1.15, J1.16, Q2.2 (S), TP17.TP
EPD_3V3_C: Q2.1 (G), R_CL1.2, TP13.TP, U2.18 (IO20)
EPD_BUSY: J1.9, TP9.TP, U2.26 (IO3)
EPD_CS: D8.1, J1.12, R9.1, TP10.TP, U2.11 (IO10)
EPD_DC: J1.11, TP11.TP, U2.5 (IO5)
EPD_RST: J1.10, TP12.TP, U2.21 (IO23)
FLASH_CS: D9.1, R5.1, U1.1 (!CS), U2.12 (IO11)
GDR: J1.2, Q3.1 (G), R4.1
GND: BOOT_BUTTON.1, BOOT_BUTTON.2, C1.2, C1_BAT.2, C1_BAT1.2, C1_BAT2.2, C2.2, C2_BAT.2, C3.-, C4_USB.2, C5.2, C5_USB.2, C6.2, C7.2, C8.2, C9.2, C10.2, C10_SUPERCAP.1, CHANGE_BUTTON.1, CHANGE_BUTTON.2, C_DELAY.2, D1.2 (GND), D3.1 (K), D6.2, D8.2, D9.2, D10.2, D11.2, D12.2, EPD_C1.1, EPD_C2.1, EPD_C5.1, EPD_C6.1, EPD_C7.1, EPD_C8.1, EPD_C9.1, EPD_C10.1, EPD_C11.1, EPD_C12.1, IC1.3 (GND), IC4.2 (VSS), J1.8, J1.17, J1.MP1, J1.MP2, J2.A1, J2.A12, J2.B1, J2.B12, J2.MP1, J2.MP2, J2.MP3, J2.MP4, J3.1, J4.G1 (GND_1), J4.G2 (GND_2), J4.G3 (GND_3), J4.G4 (GND_4), J4.P6 (VSS), MCP73831.2 (VSS), R1_PWRUSB.1, R2.1, R2-USB.2, R2-USB1.1, R2_BAT.1, R4.2, RESET_BUTTON.1, RESET_BUTTON.2, SENSOR2.1 (GND), SENSOR2.5 (SDO), SENSOR2.7 (GND), SJ1.1, TP4.TP, TP5.TP, U1.4 (GND), U1.9 (EXP), U2.1 (GND), U2.28 (GND), U2.29_1 (GND), U2.29_2 (GND), U2.29_3 (GND), U2.29_4 (GND), U2.29_5 (GND), U2.29_6 (GND), U2.29_7 (GND), U2.29_8 (GND), U2.29_9 (GND), U3.13 (GND), U4.1 (CTG), U4.4 (GND), U4.6 (QSTRT), U4.9 (EP)
GPIO8: R1.2, U2.10 (IO8)
I2C_PW: R1_PINH.2, R2-PINH.2, U2.17 (IO19)
IC2_PW: C1.1, C2.1
INT_RTC: R1_PINH1.1, TP15.TP, U2.8 (IO0), U3.3 (SQW/!INT)
IO/BOOT: BOOT_BUTTON.3, BOOT_BUTTON.4, C6.1, R_BOOT.1, U2.15 (IO9)
IO/CHANGE: C10.1, CHANGE_BUTTON.3, CHANGE_BUTTON.4, R_CHANGE.1, U2.23 (IO15)
MISO: D12.1, J4.P7 (DAT0), R8.1, TP6.TP, U1.2 (DO(IO1)), U2.27 (IO2)
MOSI: D11.1, J1.14, J4.P3 (CMD), R7.1, TP7.TP, U1.5 (DI(IO0)), U2.7 (IO7)
unnamed: EPD_C10.2, J1.22
unnamed: C1_BAT1.1, D2.1 (CATHODE), IC4.1 (VIN), IC4.3 (CE), Q1.2 (S)
unnamed: MCP73831.5 (PROG), R2_BAT.2
unnamed: EPD_C8.2, J1.20
unnamed: J2.B5, R2-USB.1
unnamed: C4.1, D3.2 (A), D4.1 (K)
unnamed: MCP73831.1 (STAT), R1_BAT.1
unnamed: CHG_LED.C, R1_BAT.2
unnamed: EPD_C7.2, J1.19
unnamed: J2.A5, R2-USB1.2
unnamed: EPD_C6.2, J1.18
unnamed: EPD_C12.2, J1.24
unnamed: D7.1 (CATHODE), R_CAPACITOR.2
unnamed: EPD_C2.2, J1.5
unnamed: EPD_C1.2, J1.4
unnamed: SENSOR2.2 (CSB), SENSOR2.6 (VDDIO), SENSOR2.8 (VDD)
unnamed: C_DELAY.1, IC1.5 (CT)
PREVGH: D5.1 (K), EPD_C9.2, J1.21
PREVGL: D4.2 (A), EPD_C11.2, J1.23
RESE: J1.3, Q3.2 (S), R3.1
RESE': R2.2, R3.2, SJ1.2
RESET: C5.1, IC1.1 (VOUT), RESET_BUTTON.3, RESET_BUTTON.4, R_RESET.1, U2.3 (EN)
RTC_RST: U2.16 (IO18), U3.4 (!RST)
RX: TP2.TP, U2.24 (RXD0/GPIO17)
SCK: D10.1, J1.13, J4.P5 (CLK), R6.1, TP8.TP, U1.6 (CLK), U2.6 (IO6)
SCL: J3.4, R2-PINH.1, SENSOR2.4 (SCK), U2.20 (IO22), U3.16 (SCL), U4.7 (SCL)
SDA: J3.3, R1_PINH.1, SENSOR2.3 (SDI), U2.19 (IO21), U3.15 (SDA), U4.8 (SDA)
SRC: C4.2, D5.2 (A), L1.1, Q3.3 (D)
SS_SD: D6.1, J4.P2 (CD/DAT3), R10.1, U2.4 (IO4)
TX: TP1.TP, U2.25 (TXD0/GPIO16)
USB_D+: D1.3 (I/O2_1), U2.14 (IO13)
USB_D-: D1.1 (I/O1_1), U2.13 (IO12)
VBAT: C2_BAT.1, MCP73831.3 (VBAT), Q1.3 (D), TP3.TP, U4.2 (CELL), U4.3 (VDD)
VBUS: C1_BAT.1, C4_USB.1, C5_USB.1, CHG_LED.A, D1.5 (VBUS), D2.2 (ANODE), MCP73831.4 (VIN), PFMF.050.1.2, Q1.1 (G), R1_PWRUSB.2, TP14.TP
VRTC: C8.1, C10_SUPERCAP.2, R_CAPACITOR.1, U3.14 (VBAT)
VUSB: J2.A4, J2.A9, J2.B4, J2.B9, PFMF.050.1.1

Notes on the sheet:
USB C connector & ESD protection
LDO Voltage Regulator
SD Card
ESP32 C6
Li-PO Battery Charging Controller
Display Type Selector
E-Paper Drive Circuit
Battery Charge Level
External NOR Flash 64MB
E-Paper Display Header
DMG2305UX-7
EPD Power
Environmental Senzor BME688
RTC Module DS3231SN
Qwiic / Stemma QT
SPI ESD Protection Lines
Voltage Supervisor + Reset & Boot / IO Button
BME688
Caramida-Stoian Cristian
Test Pads

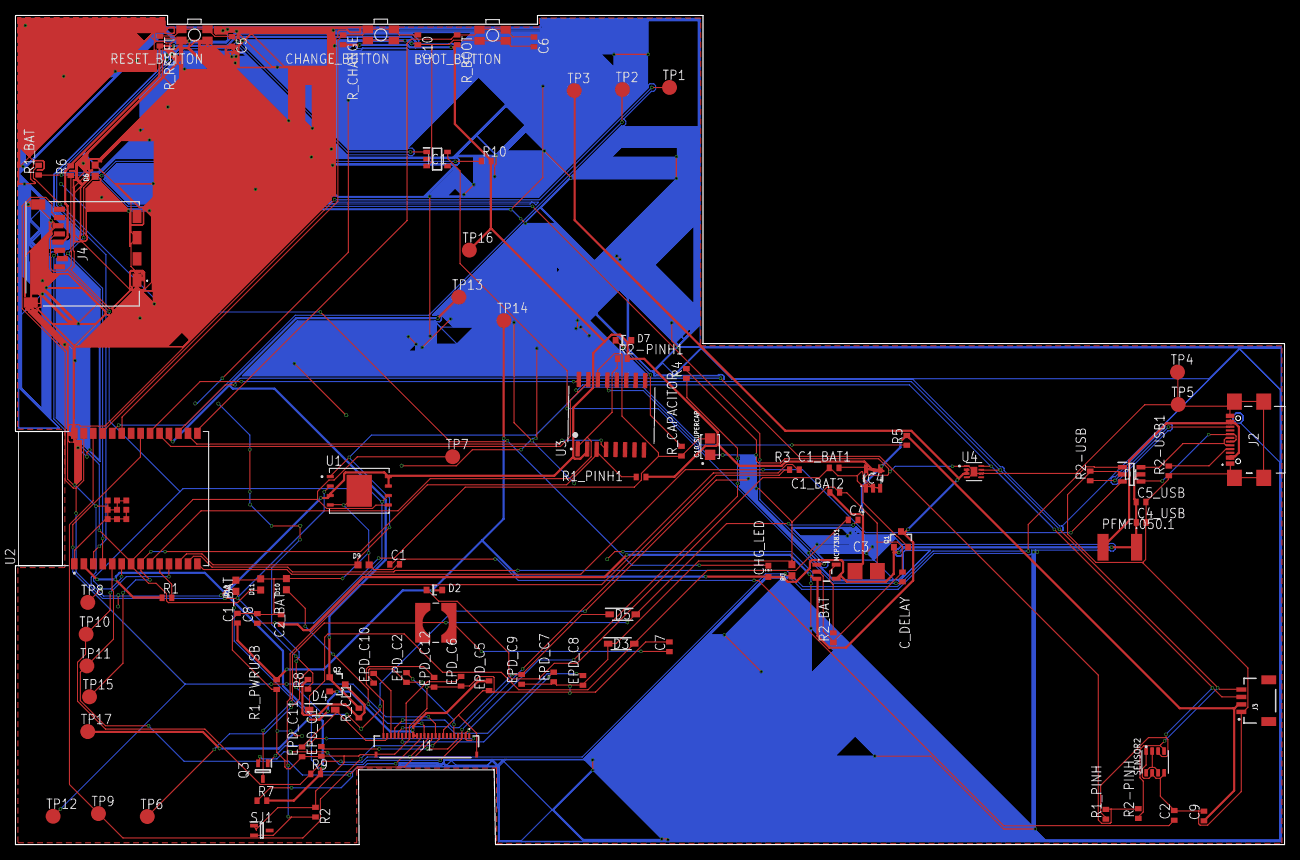
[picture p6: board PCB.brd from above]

Board: 2 copper layers, 170.2 x 111.2 mm, 103 parts (0 on the bottom side), 58 nets.

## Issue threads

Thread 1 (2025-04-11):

Schematic Issue

lalessiaa, 2025-04-11:
In chenarul Test Pads si Voltage Superviser label-urile au dimensiuni diferite, si unele se intercaleaza, fiind greu de citit.

CristiPetrisor, 2025-04-13:
Done

Closed 2025-04-13.

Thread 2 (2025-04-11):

PCB Issue

lalessiaa, 2025-04-11:
Placa nu are dimensiunile trecute in exterior, ma refer la sagetile alea trasate in exteriorul placii ( cele din enunt). La fel si la partile decupate trebuie trecute dimensiunile.

CristiPetrisor, 2025-04-13:
Solved

Closed 2025-04-13.

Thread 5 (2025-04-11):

README Issue

lalessiaa, 2025-04-11:
La Bill of Materials nu ai adaugat toate componentele ( lipsesc cele de la 3D)

CristiPetrisor, 2025-04-15:
solved

Closed 2025-04-15.

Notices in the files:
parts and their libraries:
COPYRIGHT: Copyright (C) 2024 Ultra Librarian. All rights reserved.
